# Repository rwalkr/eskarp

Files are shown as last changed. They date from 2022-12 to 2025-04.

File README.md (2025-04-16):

# Eskarp

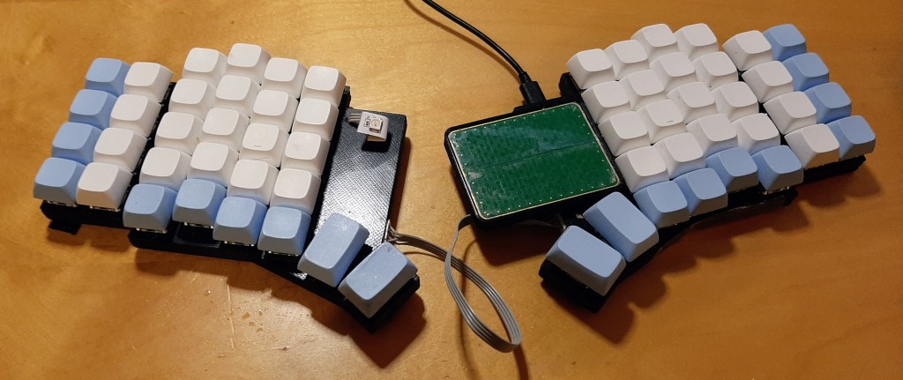
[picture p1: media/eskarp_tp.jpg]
Eskarp keyboard


An ergonomic, column staggered split keyboard with optional touchpad.
Inspired by keyboards such as [Lily58](https://github.com/kata0510/Lily58)
and [Sofle](https://josefadamcik.github.io/SofleKeyboard/).  Uses a 3D
printed case, with handwired MX compatible switches and a [Raspbery Pi
Pico](https://www.raspberrypi.com/products/raspberry-pi-pico/) controller
in each half.  Designed using [Ergogen](https://ergogen.xyz/).

## Firmware

Written in Rust, using [Keyberon](https://github.com/TeXitoi/keyberon) for
matrix scanning, debouncing and USB HID support.  Uses [RTIC](https://rtic.rs/)
runtime and [rp-pico](https://crates.io/crates/rp-pico) for Raspberry Pi Pico
support.

Each half runs the same firmware, with left / right being determined by GPIO 28
pull up/down (low = left, high = right).  Either side can act as the primary
(connected to host USB interface).  Key events from the secondary half (not
connected to USB) are sent to the primary over a serial link.

Firmware update is done on each half by resetting into bootloader mode and
mounting the RP2 mass storage device and copying the firmware build onto it.  To
reset into bootloader mode, press the reset key combo (On layer 3, the outermost
top key) five times.

Build the firmware in the `firmware/device` directory:

```
cd firmware/device
cargo build --release
# Convert to .uf2 format
elf2uf2-rs ../target/thumbv6m-none-eabi/release/eskarp
```

Copy `firmware/target/thumbv6m-none-eabi/release/eskarp.uf2` to each half of the keyboard

## Case

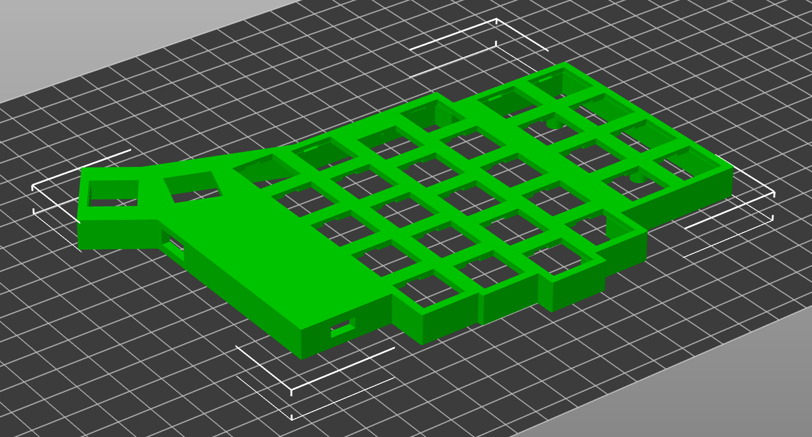
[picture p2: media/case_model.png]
Case model


The case is designed using Ergogen, version v3.1.2 - online at
<https://ergogen.cache.works/> or local install (<https://docs.ergogen.xyz/>).
See [`case/Makefile`](case/Makefile) for build commands.  Generated SVG and STL
files for the case are included in [`case/svg`](case/svg) and
[`case/stl`](case/stl).  The left and right halves are identical and should be
mirrored when slicing for 3D printing.Gcode for an Ender 3 printer with 0.8mm
nozzle is included in [`case/gcode`](case/gcode).

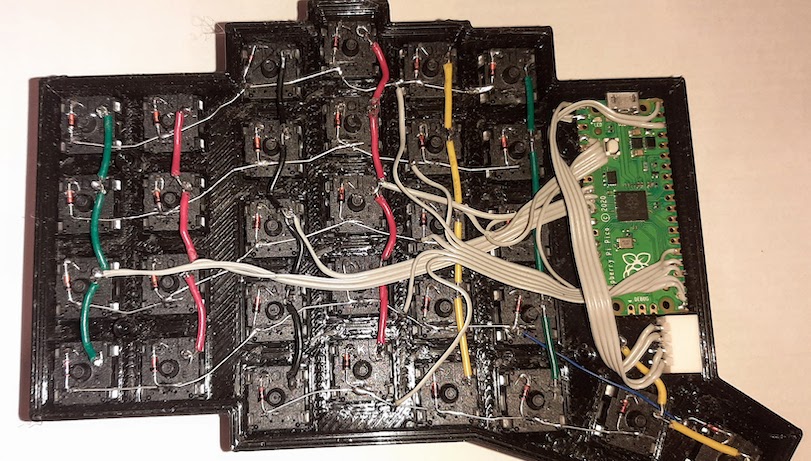
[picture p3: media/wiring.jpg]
Wiring


The keyboard matrix is handwired with RP PICO GPIOs 16-20 used for rows and
GPIOs 2-8 for the columns.  The thumb keys are both on the same column, with the
outermost on row 3 and the innermost on row 4.

Communication between the halves is via a serial link using 4 pin JST-XH
connectors.  The cable has a cross-over for RX and TX, so each half has the same
pin assingment:

1. TX (from RP Pico pin 1)
2. RX (from RP Pico pin 2)
3. Vbus (from RP Pico pin 40)
4. GND (from RP Pico pin 38)

An optional WS2812b LED can be added to indicate the current layer.  This was
added after the case was designed and printed, so a hole was drilled into the
top for the wires to the LED.

## Touchpad

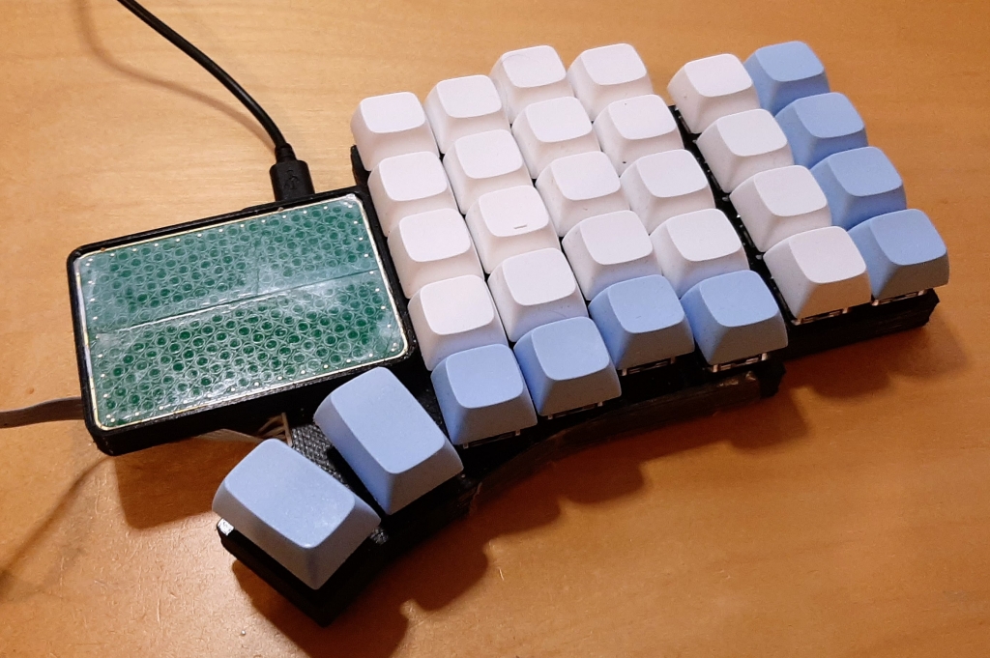
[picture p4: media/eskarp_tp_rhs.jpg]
Eskarp touchpad


An optional touchpad can be fitted to the case, using the TPS65-201A-S from
Azoteq.  This will appear as a USB HID mouse to the host computer.

The touchpad sits in a 3D printed holder and is wired to the RP Pico pins
as:

* 14: RDY (GP10)
* 15: RST (GP11)
* 16: SDA (GP12)
* 17: SCL (GP13)
* 36: VDD (3.3V)
* 38: GND

It can be fitted to either side - the firmware will detect the presence of
the touchpad - but must be on the same side as the USB connection to the
host computer (the mouse reports are not sent over the serial link to the
other half of the keyboard).

## BOM

* 3D printed case top - left and right
* 3D printed case lid - left and right
* 60x MX style switches
* 60x 1N4148 diodes
* wire
* 60x keycaps
* 8x No2 gauge, 1/4" screws
* 2x Raspberry PI Pico
* 2x JST-XH 4 pin sockets
* 2x JST-XH 4 pin plugs
* 4 wire cable
* (Optional) 1x WS2812b compatible LED
* (Optional) TPS65-201A-S available from Digikey or Mouser

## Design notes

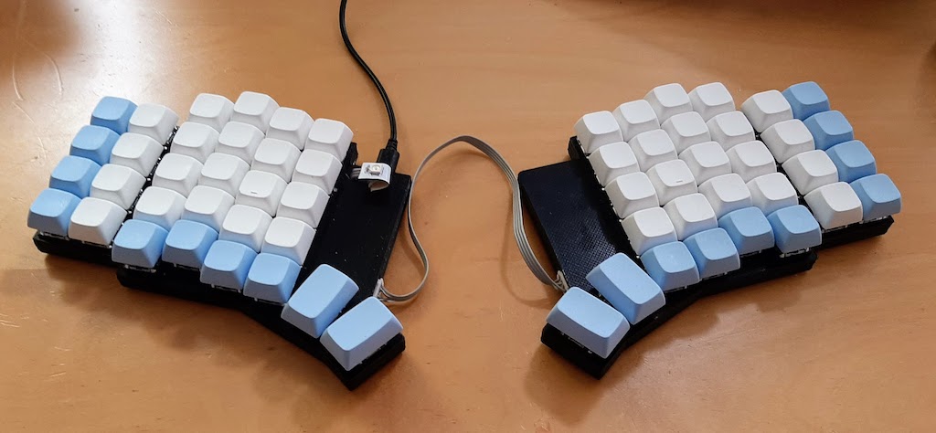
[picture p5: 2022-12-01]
media/eskarp.jpg

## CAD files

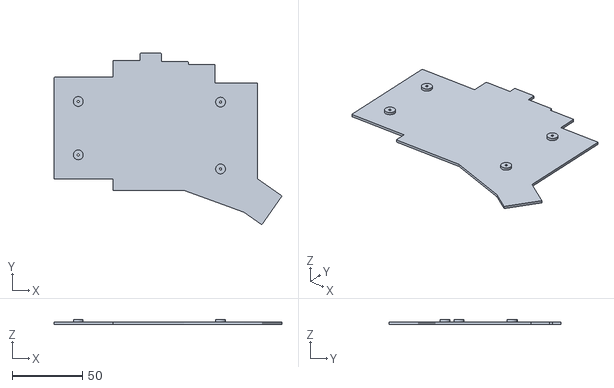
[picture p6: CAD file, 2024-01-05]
case/stl/lid.stl
162.0 x 121.9 x 3.20

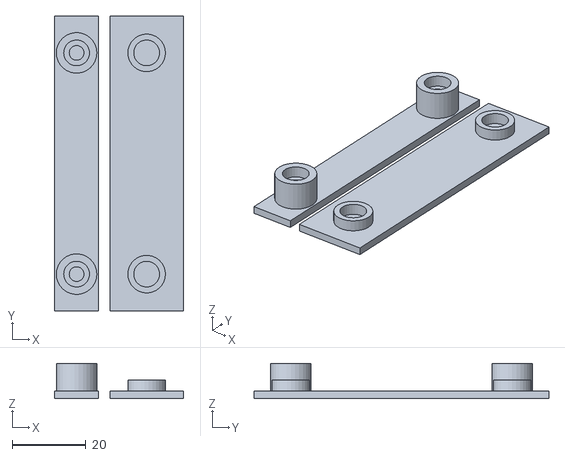
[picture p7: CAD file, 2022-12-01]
case/tent_stand/tent_stand.stl
35.0 x 80.0 x 9.50

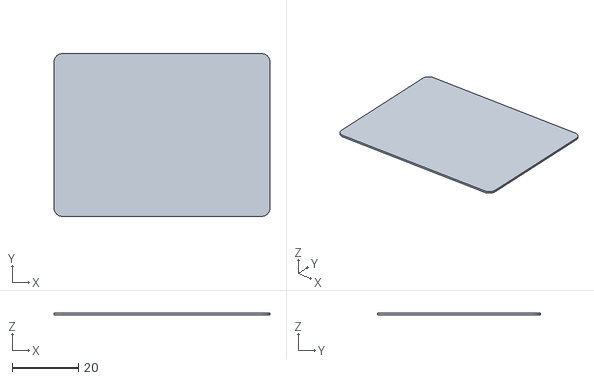
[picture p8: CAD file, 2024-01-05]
case/touchpad/touchpad_plate.stl
65.0 x 49.0 x 0.6

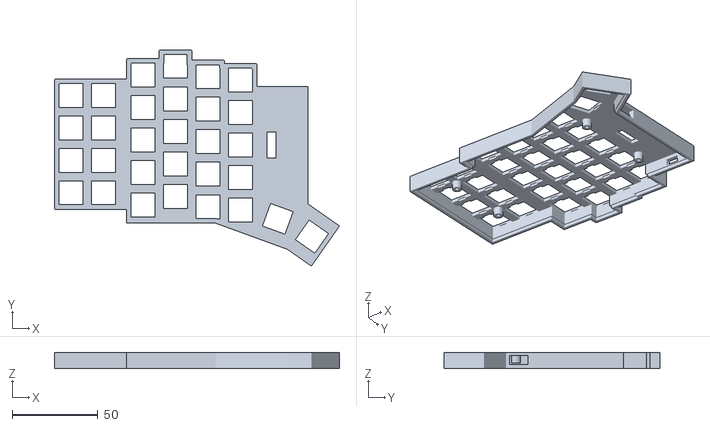
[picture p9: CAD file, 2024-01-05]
case/stl/body_tp.stl
166.3 x 126.2 x 9.60

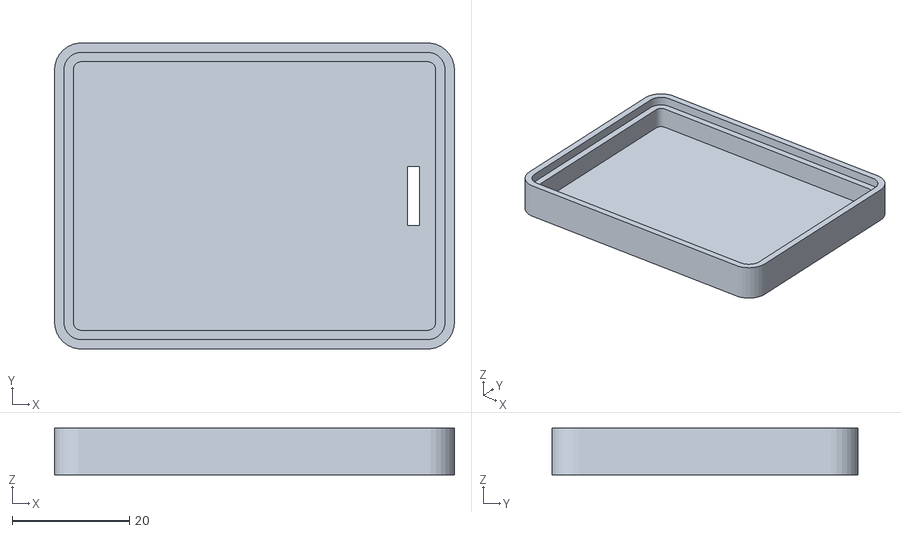
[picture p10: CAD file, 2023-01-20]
case/touchpad/touchpad.stl
68.2 x 52.1 x 8.00

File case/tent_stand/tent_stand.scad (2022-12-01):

$fn=30;

module adj_stand_top() {
    bolt_d = 4;
    bolt_h = 7;
    w = 12;
    d = 80;
    h = 2;
    h2 = 5 + 2.5;
    cube([w, d, h]);
    translate([w/2, 10, h]) {
        nut_cutout();
    }
    translate([w/2, d-10, h]) {
        nut_cutout();
    }
    module nut_cutout() {
        difference() {
            cylinder(h = h2, d = bolt_h+4);
            cylinder(h = h2+.1, d = bolt_d);
            translate([0, 0, h2-3])
                cylinder(h = 3+.1, d = bolt_h);
        }
    }
}

module adj_stand_base() {
    bolt_h = 7;
    w = 20;
    d = 80;
    h = 2;
    h2 = 3;
    cube([w, d, h]);
    translate([w/2, 10, h]) {
        socket();
    }
    translate([w/2, d-10, h]) {
        socket();
    }
    module socket() {
        difference() {
            cylinder(h = h2, d = bolt_h+3.2);
            cylinder(h = h2+.1, d = bolt_h);
        }
    }
}

adj_stand_top();
translate([15, 0, 0])
    adj_stand_base();

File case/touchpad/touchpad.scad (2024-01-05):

$fn = 30;


tp_h = 1.6;
tp_w = 65.0;
tp_d = 49.0;
tp_r = 2.5;

wall_t = 1.6;
base_t = 1.2;
plate_t = 0.6;

box_h = 9;
box_w = tp_w + 2*wall_t;
box_d = tp_d + 2*wall_t;
box_r = tp_r + wall_t;
box_inner_l = 2*wall_t;
box_inner_w = box_w - 2*box_inner_l;
box_inner_d = box_d - 2*box_inner_l;
box_inner_r = tp_r - wall_t;

module rounded_cube(x, y, z, r) {
    hull() {
        translate([r, r, 0])
        cylinder(r=r, h=z, center=false);
        translate([x-r, r, 0])
        cylinder(r=r, h=z, center=false);
        translate([x-r, y-r, 0])
        cylinder(r=r, h=z, center=false);
        translate([r, y-r, 0])
        cylinder(r=r, h=z, center=false);
    }
}


module touchpad_case() {
    difference() {
        rounded_cube(box_w, box_d, box_h, box_r);
        translate([box_inner_l, box_inner_l, base_t])
            rounded_cube(box_inner_w, box_inner_d, box_h, box_inner_r);
        translate([wall_t, wall_t, box_h-tp_h])
            rounded_cube(tp_w, tp_d, tp_h+0.1, tp_r);
        translate([box_w - 8, box_d/2-5, -0.1])
            cube([2, 10, base_t+0.2]);
    }
}

module touchpad_plate() {
    rounded_cube(tp_w-1, tp_d-1, plate_t, tp_r);
}

// touchpad_case();
touchpad_plate();

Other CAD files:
case/stl/body.stl
case/stl/body_led.stl

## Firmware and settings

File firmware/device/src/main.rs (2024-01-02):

// Keyboard firmware
#![no_main]
#![no_std]

use rp2040_panic_usb_boot as _;
use rtic::app;

mod touchpad;

#[link_section = ".config"]
static LAYOUT: &str = include_str!("layout.txt");

#[app(device = rp_pico::hal::pac,
      peripherals = true,
      dispatchers = [DMA_IRQ_0])]
mod app {
    use defmt::*;
    use defmt_rtt as _;

    use crate::touchpad;
    use ::layout::*;
    use embedded_hal::{
        digital::v2::{InputPin, OutputPin},
        serial::{Read, Write},
    };
    use frunk::{HCons, HNil};
    use fugit::{ExtU64, RateExtU32};
    use keyberon::debounce::Debouncer;
    use keyberon::layout::{CustomEvent, Event};
    use keyberon::matrix::Matrix;
    use nb::block;
    use rp2040_monotonic::Rp2040Monotonic;
    use rp_pico::hal;
    use rp_pico::hal::prelude::*;
    use rp_pico::hal::{gpio::dynpin::DynPin, pio::PIOExt, usb::UsbBus};
    use smart_leds::{SmartLedsWrite, RGB8};
    use usb_device::{
        bus::UsbBusAllocator,
        device::{UsbDeviceBuilder, UsbDeviceState, UsbVidPid},
        UsbError,
    };
    use usbd_human_interface_device::{
        device::{
            consumer::{ConsumerControlInterface, MultipleConsumerReport},
            keyboard::NKROBootKeyboardInterface,
            mouse::{WheelMouseInterface, WheelMouseReport},
        },
        hid_class::{UsbHidClass, UsbHidClassBuilder},
        page::{Consumer, Keyboard},
        UsbHidError,
    };
    use ws2812_pio::Ws2812Direct;

    type UsbCompositeInterfaceList = HCons<
        WheelMouseInterface<'static, UsbBus>,
        HCons<
            ConsumerControlInterface<'static, UsbBus>,
            HCons<NKROBootKeyboardInterface<'static, UsbBus>, HNil>,
        >,
    >;
    type UsbCompositeClass<'a> = UsbHidClass<hal::usb::UsbBus, UsbCompositeInterfaceList>;
    type UsbDevice = usb_device::device::UsbDevice<'static, hal::usb::UsbBus>;
    static mut USB_BUS: Option<UsbBusAllocator<hal::usb::UsbBus>> = None;

    // Test PID from https://pid.codes/1209/
    const VID: u16 = 0x1209;
    const PID: u16 = 0x0001;

    type UartPins = (
        hal::gpio::Pin<hal::gpio::pin::bank0::Gpio0, hal::gpio::Function<hal::gpio::Uart>>,
        hal::gpio::Pin<hal::gpio::pin::bank0::Gpio1, hal::gpio::Function<hal::gpio::Uart>>,
    );
    type UartDevice = hal::uart::UartPeripheral<hal::uart::Enabled, hal::pac::UART0, UartPins>;

    type StatusLed = Ws2812Direct<hal::pac::PIO0, hal::pio::SM0, hal::gpio::pin::bank0::Gpio26>;
    enum StatusVal {
        Layer(usize),
        Bootloader,
    }

    type IQS5xxRdyPin = hal::gpio::Pin<hal::gpio::bank0::Gpio10, hal::gpio::FloatingInput>;
    type IQS5xxRstPin = hal::gpio::Pin<hal::gpio::bank0::Gpio11, hal::gpio::PushPullOutput>;
    type I2CSDAPin = hal::gpio::Pin<hal::gpio::bank0::Gpio12, hal::gpio::FunctionI2C>;
    type I2CSCLPin = hal::gpio::Pin<hal::gpio::bank0::Gpio13, hal::gpio::FunctionI2C>;
    type IQS5xx = iqs5xx::IQS5xx<
        hal::I2C<hal::pac::I2C0, (I2CSDAPin, I2CSCLPin)>,
        IQS5xxRdyPin,
        IQS5xxRstPin,
    >;
    type Touchpad = touchpad::Touchpad<
        hal::I2C<hal::pac::I2C0, (I2CSDAPin, I2CSCLPin)>,
        IQS5xxRdyPin,
        IQS5xxRstPin,
        AppTimer,
    >;

    pub struct KeyboardState {
        matrix: Matrix<DynPin, DynPin, KBDSIZE_COLS, KBDSIZE_ROWS>,
        debouncer: Debouncer<[[bool; KBDSIZE_COLS]; KBDSIZE_ROWS]>,
    }

    impl KeyboardState {
        pub fn new(
            mut rows: [DynPin; KBDSIZE_ROWS],
            mut cols: [DynPin; KBDSIZE_COLS],
        ) -> KeyboardState {
            for r in rows.iter_mut() {
                r.into_push_pull_output();
                r.set_high().unwrap();
            }
            for c in cols.iter_mut() {
                c.into_pull_up_input();
            }

            KeyboardState {
                matrix: Matrix::new(cols, rows).unwrap(),
                debouncer: Debouncer::new(
                    [[false; KBDSIZE_COLS]; KBDSIZE_ROWS],
                    [[false; KBDSIZE_COLS]; KBDSIZE_ROWS],
                    5,
                ),
            }
        }
    }

    #[monotonic(binds = TIMER_IRQ_0, default = true)]
    type Mono = Rp2040Monotonic;
    type Duration = <Rp2040Monotonic as rtic::Monotonic>::Duration;

    const KBD_SCAN_PERIOD: Duration = Duration::millis(1);
    const USB_KBD_TICK_PERIOD: Duration = Duration::millis(1);

    #[shared]
    struct Shared {
        layout: Layout,
        usb_dev: UsbDevice,
        usb_class: UsbCompositeClass<'static>,
        uart: UartDevice,
        rxbuf: [u8; 4],
        touchpad: Option<Touchpad>,
    }

    #[local]
    struct Local {
        kbd_state: KeyboardState,
        is_left: bool,
        status_led: StatusLed,
        transform: fn(Event) -> Event,
        delay: cortex_m::delay::Delay,
    }

    #[init(local = [ layers: Option<Layers> = None])]
    fn init(c: init::Context) -> (Shared, Local, init::Monotonics) {
        // Soft-reset does not release the hardware spinlocks
        // Release them now to avoid a deadlock after debug or watchdog reset
        unsafe {
            hal::sio::spinlock_reset();
        }

        let mut resets = c.device.RESETS;
        let mut watchdog = hal::Watchdog::new(c.device.WATCHDOG);
        let clocks = hal::clocks::init_clocks_and_plls(
            rp_pico::XOSC_CRYSTAL_FREQ,
            c.device.XOSC,
            c.device.CLOCKS,
            c.device.PLL_SYS,
            c.device.PLL_USB,
            &mut resets,
            &mut watchdog,
        )
        .ok()
        .unwrap();

        let timer_mono = Rp2040Monotonic::new(c.device.TIMER);

        let sio = hal::Sio::new(c.device.SIO);
        let pins = rp_pico::Pins::new(
            c.device.IO_BANK0,
            c.device.PADS_BANK0,
            sio.gpio_bank0,
            &mut resets,
        );

        let uart_pins = (
            // UART TX (characters sent from RP2040) on pin 1 (GPIO0)
            pins.gpio0.into_mode::<hal::gpio::FunctionUart>(),
            // UART RX (characters received by RP2040) on pin 2 (GPIO1)
            pins.gpio1.into_mode::<hal::gpio::FunctionUart>(),
        );

        // Make a UART on the given pins
        let mut uart = hal::uart::UartPeripheral::new(c.device.UART0, uart_pins, &mut resets)
            .enable(
                hal::uart::UartConfig::new(
                    38400.Hz(),
                    hal::uart::DataBits::Eight,
                    None,
                    hal::uart::StopBits::One,
                ),
                clocks.peripheral_clock.freq(),
            )
            .unwrap();
        uart.enable_rx_interrupt();

        let kbd_side_pin = pins.gpio28.into_pull_up_input();
        let is_left = kbd_side_pin.is_low().unwrap();
        let transform: fn(Event) -> Event = if is_left {
            |e| e
        } else {
            |e| e.transform(|i, j| (i, j + KBDSIZE_COLS as u8))
        };

        let rows: [DynPin; KBDSIZE_ROWS] = [
            pins.gpio16.into(),
            pins.gpio17.into(),
            pins.gpio18.into(),
            pins.gpio19.into(),
            pins.gpio20.into(),
        ];
        let cols: [DynPin; KBDSIZE_COLS] = [
            pins.gpio2.into(),
            pins.gpio3.into(),
            pins.gpio4.into(),
            pins.gpio5.into(),
            pins.gpio6.into(),
            pins.gpio7.into(),
            pins.gpio8.into(),
        ];
        let kbd_state = KeyboardState::new(rows, cols);

        let mut delay =
            cortex_m::delay::Delay::new(c.core.SYST, clocks.system_clock.freq().to_Hz());

        let (mut pio, sm0, _, _, _) = c.device.PIO0.split(&mut resets);
        let mut status_led = Ws2812Direct::new(
            pins.gpio26.into_mode(),
            &mut pio,
            sm0,
            clocks.peripheral_clock.freq(),
        );
        update_status_led(&mut status_led, StatusVal::Layer(0), 0);

        // Configure I²C interface
        let sda_pin = pins.gpio12.into_mode::<hal::gpio::FunctionI2C>();
        let scl_pin = pins.gpio13.into_mode::<hal::gpio::FunctionI2C>();
        let i2c = hal::I2C::i2c0(
            c.device.I2C0,
            sda_pin,
            scl_pin,
            400.kHz(),
            &mut resets,
            &clocks.system_clock,
        );

        // create ready pin handler - using IRQs and WFI
        let rdy_pin: IQS5xxRdyPin = pins.gpio10.into_floating_input();
        rdy_pin.set_interrupt_enabled(hal::gpio::Interrupt::EdgeHigh, true);
        let rst_pin: IQS5xxRstPin = pins.gpio11.into_push_pull_output();

        info!("Init IQS5xx");
        let iqs = IQS5xx::new(i2c, 0x74, rdy_pin, rst_pin);
        let timer = AppTimer::new();
        let touchpad = match Touchpad::new(iqs, timer, &mut delay) {
            Ok(t) => Some(t),
            Err(e) => {
                warn!("IQS5xx touchpad not found: {}", e);
                None
            }
        };

        // Set up the USB driver
        let usb_bus = UsbBusAllocator::new(hal::usb::UsbBus::new(
            c.device.USBCTRL_REGS,
            c.device.USBCTRL_DPRAM,
            clocks.usb_clock,
            true,
            &mut resets,
        ));
        let usb_bus = unsafe {
            // Note (safety): This is safe as interrupts haven't been started yet
            USB_BUS = Some(usb_bus);
            USB_BUS.as_ref().unwrap()
        };

        let usb_class = UsbHidClassBuilder::new()
            .add_interface(NKROBootKeyboardInterface::default_config())
            .add_interface(ConsumerControlInterface::default_config())
            .add_interface(WheelMouseInterface::default_config())
            .build(&usb_bus);
        let usb_dev = UsbDeviceBuilder::new(usb_bus, UsbVidPid(VID, PID))
            .manufacturer("rwalkr")
            .product("eskarp")
            .serial_number(env!("CARGO_PKG_VERSION"))
            .supports_remote_wakeup(true)
            .build();

        info!("Ready!");

        kbd_scan::spawn_after(KBD_SCAN_PERIOD).unwrap();
        usb_keyboard_tick::spawn_after(USB_KBD_TICK_PERIOD).unwrap();

        *c.local.layers = Some(layout::make_keymap(crate::LAYOUT).unwrap());
        let layout = Layout::new(c.local.layers.as_ref().unwrap());
        let shared = Shared {
            layout: layout,
            usb_dev,
            usb_class,
            uart,
            rxbuf: [0; 4],
            touchpad,
        };
        let local = Local {
            kbd_state,
            is_left,
            status_led,
            transform,
            delay,
        };
        (shared, local, init::Monotonics(timer_mono))
    }

    #[task(binds = USBCTRL_IRQ, shared = [usb_dev, usb_class])]
    fn usbctrl(c: usbctrl::Context) {
        let usb_dev = c.shared.usb_dev;
        let usb_class = c.shared.usb_class;
        (usb_dev, usb_class).lock(|usb_dev, usb_class| {
            if usb_dev.poll(&mut [usb_class]) {
                // need to read any incoming report to clear the interface,
                // even though we don't do anything with it
                let interface = usb_class.interface::<NKROBootKeyboardInterface<'_, _>, _>();
                match interface.read_report() {
                    Err(UsbError::WouldBlock) => {}
                    Err(e) => {
                        core::panic!("Failed to read keyboard report: {:?}", e)
                    }
                    Ok(_) => {}
                }
            }
        });
    }

    #[task(binds = IO_IRQ_BANK0, priority = 2, shared = [touchpad])]
    fn io_irq(c: io_irq::Context) {
        let mut touchpad = c.shared.touchpad;

        touchpad.lock(|touchpad| {
            if let Some(touchpad) = touchpad {
                touchpad.clear_irq(|pin: &mut IQS5xxRdyPin| {
                    if pin.interrupt_status(hal::gpio::Interrupt::EdgeHigh) {
                        // clear the IRQ
                        pin.clear_interrupt(hal::gpio::Interrupt::EdgeHigh);
                    }
                });

                touchpad.process(|rep, delay| {
                    send_mouse_report::spawn_after(Duration::millis(delay as u64), rep).ok();
                });
            }
        });
    }

    #[task(local = [kbd_state, transform, delay], shared = [uart])]
    fn kbd_scan(c: kbd_scan::Context) {
        let transform = c.local.transform;
        let kbd_state = c.local.kbd_state;
        let delay = c.local.delay;
        let matrix_state = kbd_state
            .matrix
            .get_with_delay(|| {
                delay.delay_us(10);
            })
            .unwrap();
        let events = kbd_state.debouncer.events(matrix_state);
        let mut uart = c.shared.uart;
        uart.lock(|uart| {
            for event in events {
                let event = transform(event);
                for &b in &ser(event) {
                    block!(uart.write(b)).unwrap();
                }
                handle_event::spawn(event).unwrap();
            }
        });
        tick_keyboard::spawn().unwrap();
        kbd_scan::spawn_after(KBD_SCAN_PERIOD).unwrap();
    }

    #[task(binds = UART0_IRQ, shared = [uart, rxbuf])]
    fn uart_rx(c: uart_rx::Context) {
        (c.shared.uart, c.shared.rxbuf).lock(|uart, rxbuf| {
            while let Ok(b) = uart.read() {
                rxbuf.rotate_left(1);
                rxbuf[3] = b;

                if rxbuf[3] == b'\n' {
                    if let Ok(event) = de(&rxbuf[..]) {
                        handle_event::spawn(event).unwrap();
                    }
                }
            }
        });
    }

    #[task(capacity = 8, shared = [layout])]
    fn handle_event(mut c: handle_event::Context, event: Event) {
        c.shared.layout.lock(|layout| layout.event(event));
    }

    #[task(shared = [layout],
           local = [is_left, status_led, cur_layer: usize = 0, rset_left: bool = false, rset_count: u32 = 0])]
    fn tick_keyboard(c: tick_keyboard::Context) {
        let mut layout = c.shared.layout;
        let is_left = *c.local.is_left;
        let status_led = c.local.status_led;
        let cur_layer = c.local.cur_layer;
        let rset_left = c.local.rset_left;
        let rset_count = c.local.rset_count;
        layout.lock(|layout| {
            match layout.tick() {
                // reset if reset key pressed 5 times
                CustomEvent::Release(CustomKey::Reset(k)) => {
                    if *rset_count == 0 || k.is_left() != *rset_left {
                        *rset_left = k.is_left();
                        *rset_count = 1;
                    } else if k.is_left() == *rset_left {
                        *rset_count += 1;
                    } else {
                        *rset_count = 0;
                    }
                    if *rset_count >= 5 {
                        *rset_count = 0;
                        update_status_led(status_led, StatusVal::Bootloader, 0);
                        if *rset_left == is_left {
                            do_reset();
                        }
                    } else {
                        update_status_led(status_led, StatusVal::Layer(*cur_layer), *rset_count);
                    }
                }
                CustomEvent::Press(CustomKey::Media(k)) => {
                    let r = MultipleConsumerReport {
                        codes: [
                            *k,
                            Consumer::Unassigned,
                            Consumer::Unassigned,
                            Consumer::Unassigned,
                        ],
                    };
                    send_consumer_report::spawn(r).unwrap();
                }
                CustomEvent::Release(CustomKey::Media(_)) => {
                    send_consumer_report::spawn(MultipleConsumerReport::default()).unwrap();
                }
                _ => {}
            };

            if layout.current_layer() != *cur_layer {
                *cur_layer = layout.current_layer();
                if *cur_layer != 3 {
                    *rset_count = 0;
                }
                update_status_led(status_led, StatusVal::Layer(*cur_layer), *rset_count);
            }

            let keycodes: heapless::Vec<Keyboard, 70> = layout.keycodes().collect();
            send_keyboard_report::spawn(keycodes).unwrap();
        });
    }

    #[task(shared = [usb_class])]
    fn usb_keyboard_tick(c: usb_keyboard_tick::Context) {
        let mut usb_class = c.shared.usb_class;
        usb_class.lock(|usb_class| {
            match usb_class
                .interface::<NKROBootKeyboardInterface<'_, _>, _>()
                .tick()
            {
                Err(UsbHidError::WouldBlock) | Err(UsbHidError::Duplicate) | Ok(_) => {}
                Err(e) => {
                    core::panic!("Failed to process keyboard tick: {:?}", e);
                }
            }
        });
        usb_keyboard_tick::spawn_after(USB_KBD_TICK_PERIOD).unwrap();
    }

    #[task(shared = [usb_dev, usb_class], capacity = 8)]
    fn send_keyboard_report(c: send_keyboard_report::Context, report: heapless::Vec<Keyboard, 70>) {
        let usb_dev = c.shared.usb_dev;
        let usb_class = c.shared.usb_class;
        (usb_dev, usb_class).lock(|usb_dev, usb_class| {
            if usb_dev.state() != usb_device::device::UsbDeviceState::Configured {
                return;
            }
            let is_any_key_pressed = !report.is_empty();
            match usb_class
                .interface::<NKROBootKeyboardInterface<'_, _>, _>()
                .write_report(report)
            {
                Err(UsbHidError::WouldBlock) | Err(UsbHidError::Duplicate) | Ok(_) => {}
                Err(e) => {
                    core::panic!("Failed to write keyboard report: {:?}", e);
                }
            }

            if is_any_key_pressed
                && usb_dev.state() == UsbDeviceState::Suspend
                && usb_dev.remote_wakeup_enabled()
            {
                usb_dev.bus().remote_wakeup();
            }
        });
    }

    #[task(shared = [usb_class], capacity = 8)]
    fn send_consumer_report(c: send_consumer_report::Context, report: MultipleConsumerReport) {
        let mut usb_class = c.shared.usb_class;
        usb_class.lock(|usb_class| {
            match usb_class
                .interface::<ConsumerControlInterface<'_, _>, _>()
                .write_report(&report)
            {
                Err(UsbError::WouldBlock) | Ok(_) => {}
                Err(e) => {
                    core::panic!("Failed to write consumer report: {:?}", e);
                }
            }
        });
    }

    #[task(shared = [usb_class], capacity = 8)]
    fn send_mouse_report(c: send_mouse_report::Context, report: WheelMouseReport) {
        let mut usb_class = c.shared.usb_class;
        usb_class.lock(|usb_class| {
            match usb_class
                .interface::<WheelMouseInterface<'_, _>, _>()
                .write_report(&report)
            {
                Err(UsbHidError::WouldBlock) | Err(UsbHidError::Duplicate) | Ok(_) => {}
                Err(e) => {
                    core::panic!("Failed to write mouse report: {:?}", e);
                }
            }
        });
    }

    #[task(shared = [touchpad])]
    fn move_tick(c: move_tick::Context) {
        let mut touchpad = c.shared.touchpad;

        touchpad.lock(|touchpad| {
            if let Some(touchpad) = touchpad {
                touchpad.tick(&mut |report| {
                    send_mouse_report::spawn(report).ok();
                });
            }
        });
    }

    fn de(bytes: &[u8]) -> Result<Event, ()> {
        match *bytes {
            [b'P', i, j, b'\n'] => Ok(Event::Press(i, j)),
            [b'R', i, j, b'\n'] => Ok(Event::Release(i, j)),
            _ => Err(()),
        }
    }

    fn ser(e: Event) -> [u8; 4] {
        match e {
            Event::Press(i, j) => [b'P', i, j, b'\n'],
            Event::Release(i, j) => [b'R', i, j, b'\n'],
        }
    }

    fn update_status_led(status_led: &mut StatusLed, status: StatusVal, rset_count: u32) {
        let led_color: RGB8 = match status {
            StatusVal::Layer(1) => (0, 0, 8),
            StatusVal::Layer(2) => (0, 8, 0),
            StatusVal::Layer(3) => (8 + 8 * rset_count as u8, 0, 0),
            StatusVal::Bootloader => (8, 4, 0),
            _ => (0, 0, 0),
        }
        .into();
        status_led.write([led_color].iter().copied()).unwrap();
    }

    fn do_reset() {
        hal::rom_data::reset_to_usb_boot(0, 0);
    }

    pub struct AppTimer {
        tick_handle: Option<move_tick::SpawnHandle>,
    }

    impl AppTimer {
        fn new() -> Self {
            AppTimer { tick_handle: None }
        }
    }

    impl touchpad::Timer for AppTimer {
        fn start(&mut self, delay: u64) {
            self.cancel();
            self.tick_handle = move_tick::spawn_after(delay.millis()).ok();
        }

        fn cancel(&mut self) {
            let old_handle = self.tick_handle.take();
            if let Some(h) = old_handle {
                h.cancel().ok();
            }
        }

        fn reschedule(&mut self, interval: u64) {
            self.tick_handle = move_tick::spawn_after(interval.millis()).ok();
        }
    }
}

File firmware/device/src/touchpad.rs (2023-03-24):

// #![no_std]

use defmt::*;
// use defmt_rtt as _;
use micromath::F32Ext;

use embedded_hal::blocking::delay::DelayMs;
use usbd_human_interface_device::device::mouse::WheelMouseReport;

pub type Result<T> = core::result::Result<T, iqs5xx::Error>;

#[derive(Format)]
pub enum MovementState {
    Idle,
    Contact {
        dx: i16,
        dy: i16,
        buttons: u8,
    },
    Coasting {
        v0: f32,
        px: f32,
        py: f32,
        v: f32,
        dx: f32,
        dy: f32,
        buttons: u8,
    },
}

pub trait Timer {
    fn start(&mut self, delay: u64);
    fn cancel(&mut self);
    fn reschedule(&mut self, interval: u64);
}

pub struct Movement<T: Timer> {
    move_state: MovementState,
    timer: T,
}

impl<T: Timer> Movement<T> {
    const COAST_TICK_INITIAL_DELAY: u64 = 15; // slightly longer than active report interval
    const COAST_TICK_INTERVAL: u64 = 10;
    const FRICTION: f32 = 0.90;
    const COAST_START_THRESHOLD: f32 = 16.;
    const COAST_END_THRESHOLD: f32 = 1.;

    pub fn new(timer: T) -> Self {
        Movement {
            move_state: MovementState::Idle,
            timer: timer,
        }
    }

    fn contact(&mut self, dx: i16, dy: i16, buttons: u8) -> Option<MouseReport> {
        let mx = map_v(dx);
        let my = map_v(dy);
        let report = MouseReport::default()
            .pos(mx as i8, my as i8)
            .buttons(buttons);
        self.move_state = MovementState::Contact { dx, dy, buttons };
        self.timer.start(Self::COAST_TICK_INITIAL_DELAY);
        Some(report)
    }

    fn stop(&mut self) {
        self.move_state = MovementState::Idle;
        self.timer.cancel();
    }

    fn tick(&mut self) -> Option<MouseReport> {
        info!("tick: {}", self.move_state);
        let (report, new_state) = match self.move_state {
            MovementState::Idle => (None, MovementState::Idle),
            MovementState::Contact { dx, dy, buttons } => {
                let vx = map_v(dx);
                let vy = map_v(dy);
                let v0 = (vx * vx + vy * vy).sqrt();
                // info!("  vx: {}, vy: {}, v0: {}", vx, vy, v0);
                if v0 >= Self::COAST_START_THRESHOLD {
                    let px = vx as f32 / v0;
                    let py = vy as f32 / v0;
                    let v = v0 * Self::FRICTION;
                    let (dx, rx) = update_v(v, px, 0.);
                    let (dy, ry) = update_v(v, py, 0.);
                    let report = MouseReport::default().pos(rx, ry).buttons(buttons);
                    (
                        Some(report),
                        MovementState::Coasting {
                            v0,
                            px,
                            py,
                            v,
                            dx,
                            dy,
                            buttons,
                        },
                    )
                } else {
                    (None, MovementState::Idle)
                }
            }
            MovementState::Coasting {
                v0,
                px,
                py,
                v,
                dx,
                dy,
                buttons,
            } => {
                if v >= Self::COAST_END_THRESHOLD {
                    let v = v * Self::FRICTION;
                    let (dx, rx) = update_v(v, px, dx);
                    let (dy, ry) = update_v(v, py, dy);
                    let report = if rx != 0 || ry != 0 {
                        Some(MouseReport::default().pos(rx, ry).buttons(buttons))
                    } else {
                        None
                    };
                    (
                        report,
                        MovementState::Coasting {
                            v0,
                            px,
                            py,
                            v,
                            dx,
                            dy,
                            buttons,
                        },
                    )
                } else {
                    (None, MovementState::Idle)
                }
            }
        };
        if let MovementState::Coasting { .. } = new_state {
            self.timer.reschedule(Self::COAST_TICK_INTERVAL);
        }
        self.move_state = new_state;
        report
    }
}

fn update_v(vel: f32, prop: f32, residual: f32) -> (f32, i8) {
    let new = residual + vel * prop;
    let rep = new as i8;
    let residual = new - rep as f32;
    (residual, rep)
}

fn map_v(d: i16) -> f32 {
    d.signum() as f32 * (0.7 * (d.abs() as f32)).powf(1.6)
}

pub struct Touchpad<I2C, RDY, RST, T: Timer> {
    iqs: iqs5xx::IQS5xx<I2C, RDY, RST>,
    resolution: (u16, u16),
    movement: Movement<T>,
    scroll_credit: i16,
}

#[derive(Clone, Debug, Default)]
struct MouseReport(WheelMouseReport);

impl MouseReport {
    pub fn buttons(mut self, buttons: u8) -> Self {
        self.0.buttons = buttons;
        self
    }

    pub fn pos(mut self, x: i8, y: i8) -> Self {
        self.0.x = x;
        self.0.y = y;
        self
    }

    pub fn wheel(mut self, v: i8) -> Self {
        self.0.vertical_wheel = v;
        self
    }

    pub fn pan(mut self, v: i8) -> Self {
        self.0.horizontal_wheel = v;
        self
    }
}

impl From<MouseReport> for WheelMouseReport {
    fn from(r: MouseReport) -> Self {
        r.0
    }
}
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

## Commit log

2022-10-07 Case and build scripts
2022-10-07 STL models / drawings for case
    [body.stl, lid.stl]
2022-12-01 Update rp-pico version. Use IRQ for UART
2022-12-01 Update rp-pico version
2022-12-01 Add WS2812 LED to indicate status
2022-12-01 Tenting stand
    [tent_stand.scad, tent_stand.stl]
2022-12-01 Update dependencies, use monotonic timer
2022-12-01 Reboot to bootloader on panic
    [main.rs]
2022-12-01 Start USB last
    Avoids problems if too long spent in init to service USB interrupts
    [main.rs]
2022-12-01 Use custom USB VID/PID and set manufacturer & product strings
2023-01-20 Update LED state when resetting either side
    [main.rs]
2023-01-20 Holder for touchpad
    [touchpad.scad, touchpad.stl]
2023-03-24 Use usb-human-interface-device package for USB HID
    NKRO boot protocol allows use of keyboard in BIOS and adds NKRO
    Removes local USB HID descriptors for mouse & media keys
2023-06-10 Fix pin numbering for touchpad
2023-09-10 Place layout at fixed address in flash
    [main.rs]
2024-01-05 Add LED / touchpad cutouts to case
    [body_led.stl, body_tp.stl]
2024-01-05 gcode for case with LED / touchpad cutouts on Ender 3 0.4mm
2024-01-05 Add top skin for touchpad
    [touchpad.scad]
2024-01-05 Update to ergogen 4
    [body.stl, body_led.stl, body_tp.stl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]
2024-01-05 touchpad plate outputs
    [touchpad_plate.stl]
2025-04-16 Use probe-rs to run firmware
